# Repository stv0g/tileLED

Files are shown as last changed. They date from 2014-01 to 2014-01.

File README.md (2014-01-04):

tileLED
=======

A very minimalistic driver for 8x8 LED dot matrix displays.

Based on an ATmega8 this board can drive a simple LED matrix displays. There is no real "driver" circuit on the board. We just use the GPIOs of the AVR mcu to sink/source the LED current.

According to the ATmega8 datasheet this usage is a bit out of spec, but tests with 3 Volt button cells were successful. Also 5 Volt supplies are okay.

The source code includes a simple demonstration application. Paired with a DS1820 digital temperature sensor, the display shows the current temperature and records the minimal and maximal temperature ever measured.

A Blog post on http://www.steffenvogel.de will follow.

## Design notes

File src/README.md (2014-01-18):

This is a simple demo application

#### Fuses for the ATmega8

We use the internal 8 MHz oszilator:

Low = 0xd4
High = 0xd9

use 'make fuses' to program using avrdude

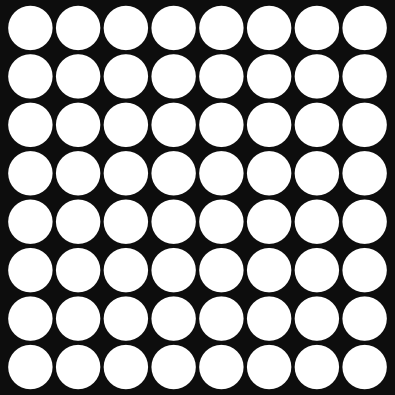
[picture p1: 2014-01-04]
schematic/v4/tile_texture.png

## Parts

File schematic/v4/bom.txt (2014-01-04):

ATmega32u4	QFN44				ok
NRF8001		QFN32				ok

micro USB					ok
3.0 V LDO VR					ok
16 Mhz Quarz / Oszillator

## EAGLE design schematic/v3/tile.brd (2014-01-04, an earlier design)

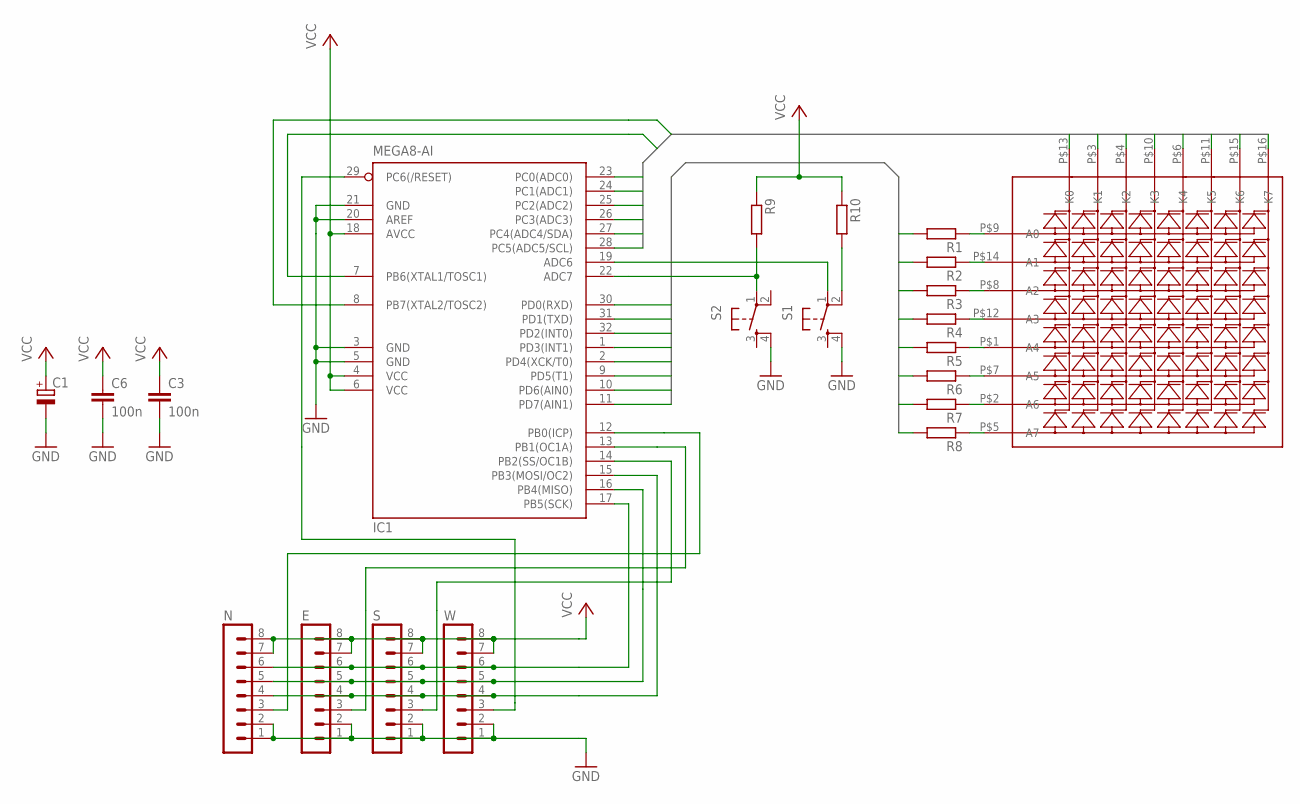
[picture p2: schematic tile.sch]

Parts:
C1: CPOL-EUB; PANASONIC_B
C3, C6: 100n; C0805
E: MA08-1
IC1: MEGA8-AI; TQFP32-08
N: MA08-1
R1, R2, R3, R4, R5, R6, R7, R8, R9, R10: R-EU_M0805; M0805
S: MA08-1
S1, S2: TAC_SWITCHSMD; TACTILE_SWITCH_SMD
U$1: LED-MATRIX
W: MA08-1

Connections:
A0: IC1.30 (PD0(RXD)), R1.2
A1: IC1.31 (PD1(TXD)), R2.2
A2: IC1.32 (PD2(INT0)), R3.2
A3: IC1.1 (PD3(INT1)), R4.2
A4: IC1.2 (PD4(XCK/T0)), R5.2
A5: IC1.9 (PD5(T1)), R6.2
A6: IC1.10 (PD6(AIN0)), R7.2
A7: IC1.11 (PD7(AIN1)), R8.2
GND: C1.-, C3.2, C6.2, E.1, E.2, IC1.3 (GND), IC1.5 (GND), IC1.20 (AREF), IC1.21 (GND), N.1, N.2, S.1, S.2, S1.4, S2.4, W.1, W.2
K0: IC1.23 (PC0(ADC0)), U$1.P$13 (K0)
K1: IC1.24 (PC1(ADC1)), U$1.P$3 (K1)
K2: IC1.25 (PC2(ADC2)), U$1.P$4 (K2)
K3: IC1.26 (PC3(ADC3)), U$1.P$10 (K3)
K4: IC1.27 (PC4(ADC4/SDA)), U$1.P$6 (K4)
K5: IC1.28 (PC5(ADC5/SCL)), U$1.P$11 (K5)
K6: IC1.7 (PB6(XTAL1/TOSC1)), U$1.P$15 (K6)
K7: IC1.8 (PB7(XTAL2/TOSC2)), U$1.P$16 (K7)
unnamed: IC1.19 (ADC6), S1.1
unnamed: IC1.22 (ADC7), R9.2, S2.1
unnamed: E.4, IC1.15 (PB3(MOSI/OC2)), N.4, S.4, W.4
unnamed: R10.2, S1.2
unnamed: IC1.14 (PB2(SS/OC1B)), S.3
unnamed: E.6, IC1.17 (PB5(SCK)), N.6, S.6, W.6
unnamed: IC1.29 (PC6(/RESET)), W.3
unnamed: E.5, IC1.16 (PB4(MISO)), N.5, S.5, W.5
unnamed: IC1.12 (PB0(ICP)), N.3
unnamed: E.3, IC1.13 (PB1(OC1A))
NA0: R1.1, U$1.P$9 (A0)
NA1: R2.1, U$1.P$14 (A1)
NA2: R3.1, U$1.P$8 (A2)
NA3: R4.1, U$1.P$12 (A3)
NA4: R5.1, U$1.P$1 (A4)
NA5: R6.1, U$1.P$7 (A5)
NA6: R7.1, U$1.P$2 (A6)
NA7: R8.1, U$1.P$5 (A7)
VCC: C1.+, C3.1, C6.1, E.7, E.8, IC1.4 (VCC), IC1.6 (VCC), IC1.18 (AVCC), N.7, N.8, R9.1, R10.1, S.7, S.8, W.7, W.8

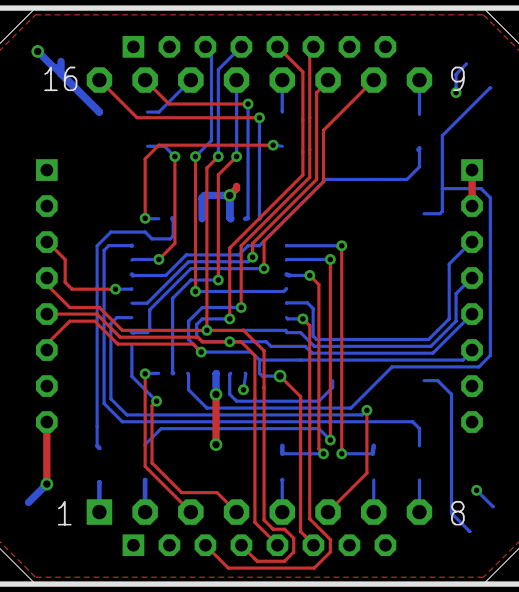
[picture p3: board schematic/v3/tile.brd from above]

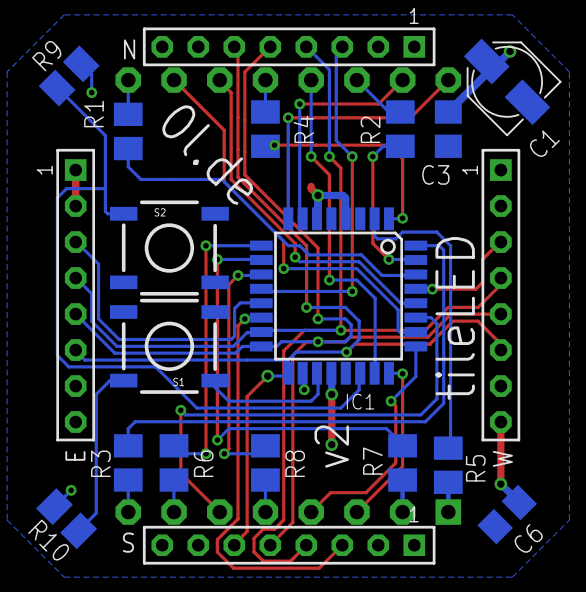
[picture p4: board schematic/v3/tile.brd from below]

Board: 2 copper layers, 21 parts (20 on the bottom side), 36 nets.

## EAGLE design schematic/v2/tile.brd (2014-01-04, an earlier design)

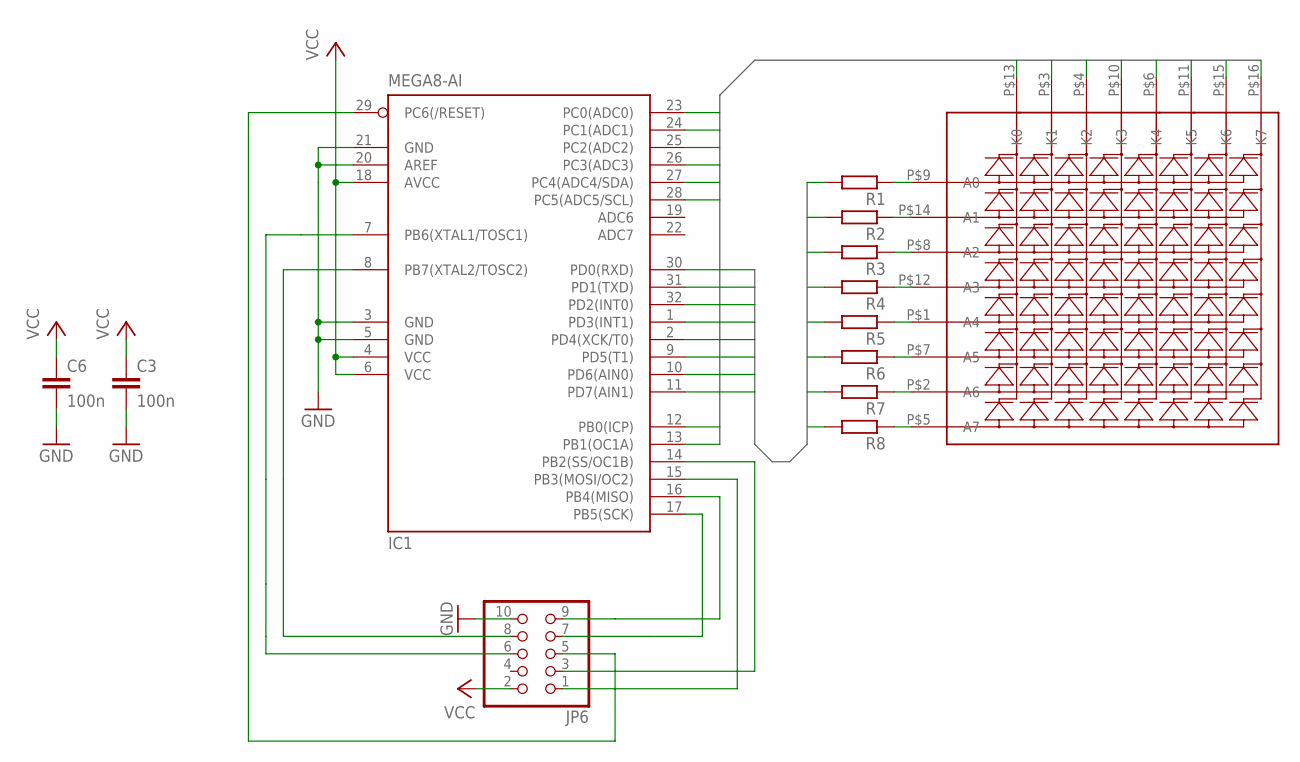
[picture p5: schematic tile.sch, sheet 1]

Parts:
C3, C6: 100n; C0805
IC1: MEGA8-AI; TQFP32-08
JP6: PINHD-2X5_2.54; 2X05
R1, R2, R3, R4, R5, R6, R7, R8: R-EU_M0805; M0805
U$1: LED-MATRIX

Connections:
A0: IC1.30 (PD0(RXD)), R1.1, R1.2, U$1.P$9 (A0)
A1: IC1.31 (PD1(TXD)), R2.1, R2.2, U$1.P$14 (A1)
A2: IC1.32 (PD2(INT0)), R3.1, R3.2, U$1.P$8 (A2)
A3: IC1.1 (PD3(INT1)), R4.1, R4.2, U$1.P$12 (A3)
A4: IC1.2 (PD4(XCK/T0)), R5.1, U$1.P$1 (A4)
A5: IC1.9 (PD5(T1)), R5.2, R6.1, R6.2, U$1.P$7 (A5)
A6: IC1.10 (PD6(AIN0)), R7.1, R7.2, U$1.P$2 (A6)
A7: IC1.11 (PD7(AIN1)), R8.1, R8.2, U$1.P$5 (A7)
GND: C3.2, C6.2, IC1.3 (GND), IC1.5 (GND), IC1.20 (AREF), IC1.21 (GND), JP6.10; also elsewhere on the board
K0: IC1.23 (PC0(ADC0)), U$1.P$13 (K0)
K1: IC1.24 (PC1(ADC1)), U$1.P$3 (K1)
K2: IC1.25 (PC2(ADC2)), U$1.P$4 (K2)
K3: IC1.26 (PC3(ADC3)), U$1.P$10 (K3)
K4: IC1.27 (PC4(ADC4/SDA)), U$1.P$6 (K4)
K5: IC1.28 (PC5(ADC5/SCL)), U$1.P$11 (K5)
K6: IC1.12 (PB0(ICP)), U$1.P$15 (K6)
K7: IC1.13 (PB1(OC1A)), U$1.P$16 (K7)
unnamed: IC1.17 (PB5(SCK)), JP6.7
unnamed: IC1.8 (PB7(XTAL2/TOSC2)), JP6.8
unnamed: IC1.29 (PC6(/RESET)), JP6.5
unnamed: IC1.14 (PB2(SS/OC1B)), JP6.3
unnamed: IC1.16 (PB4(MISO)), JP6.9
unnamed: IC1.15 (PB3(MOSI/OC2)), JP6.1
unnamed: IC1.7 (PB6(XTAL1/TOSC1)), JP6.6
VCC: C3.1, C6.1, IC1.4 (VCC), IC1.6 (VCC), IC1.18 (AVCC), JP6.2; also elsewhere on the board

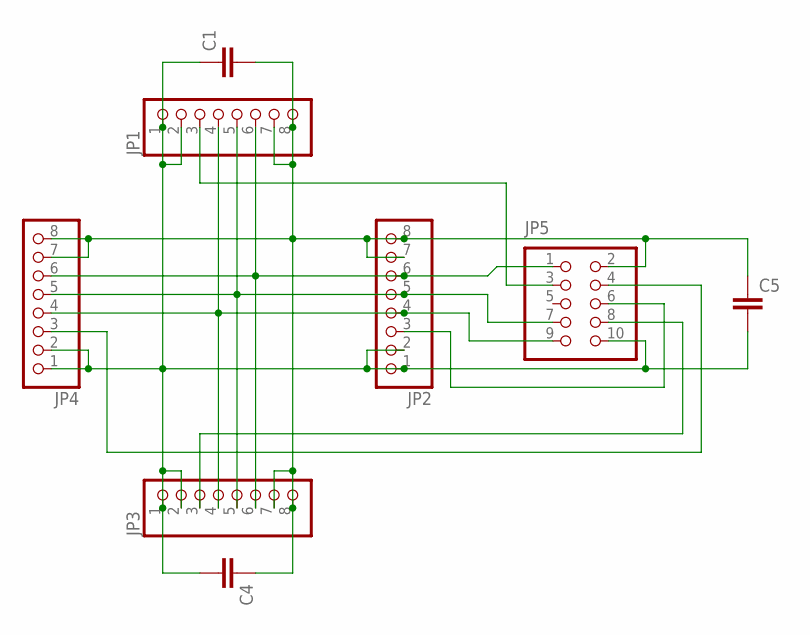
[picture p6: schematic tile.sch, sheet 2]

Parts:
C1, C4, C5: C-EUC0805; C0805
JP1, JP2, JP3, JP4: PINHD-1X8_2.00; 1X08M
JP5: PINHD-2X5_2.54; 2X05

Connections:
GND: C1.1, C4.2, C5.2, JP1.1, JP1.2, JP2.1, JP2.2, JP3.1, JP3.2, JP4.1, JP4.2, JP5.10; also elsewhere on the board
unnamed: JP4.3, JP5.4
unnamed: JP3.3, JP5.8
unnamed: JP2.3, JP5.6
unnamed: JP1.3, JP5.3
unnamed: JP1.6, JP2.6, JP3.6, JP4.6, JP5.1
unnamed: JP1.5, JP2.5, JP3.5, JP4.5, JP5.7
unnamed: JP1.4, JP2.4, JP3.4, JP4.4, JP5.9
VCC: C1.2, C4.1, C5.1, JP1.7, JP1.8, JP2.7, JP2.8, JP3.7, JP3.8, JP4.7, JP4.8, JP5.2; also elsewhere on the board

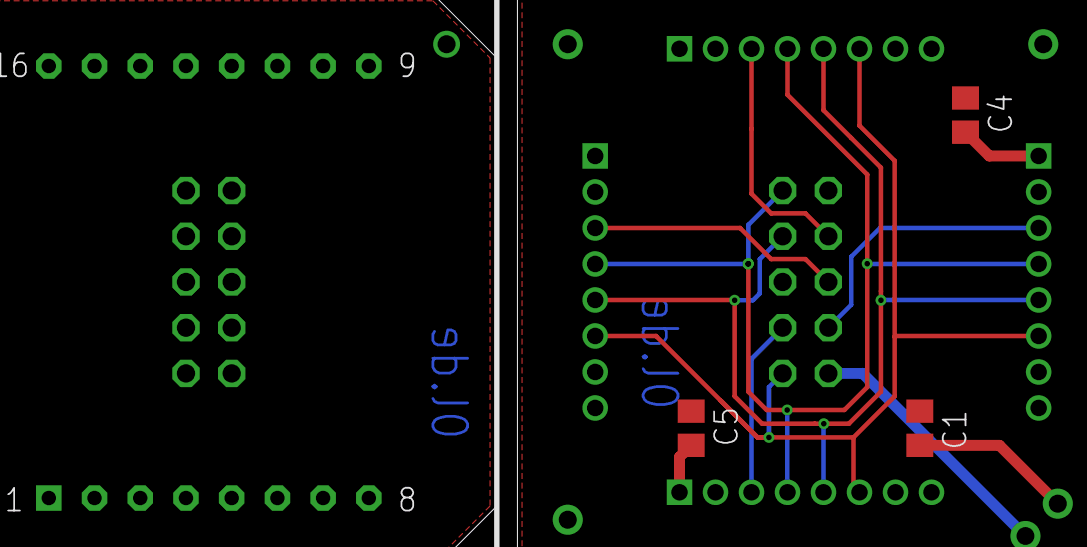
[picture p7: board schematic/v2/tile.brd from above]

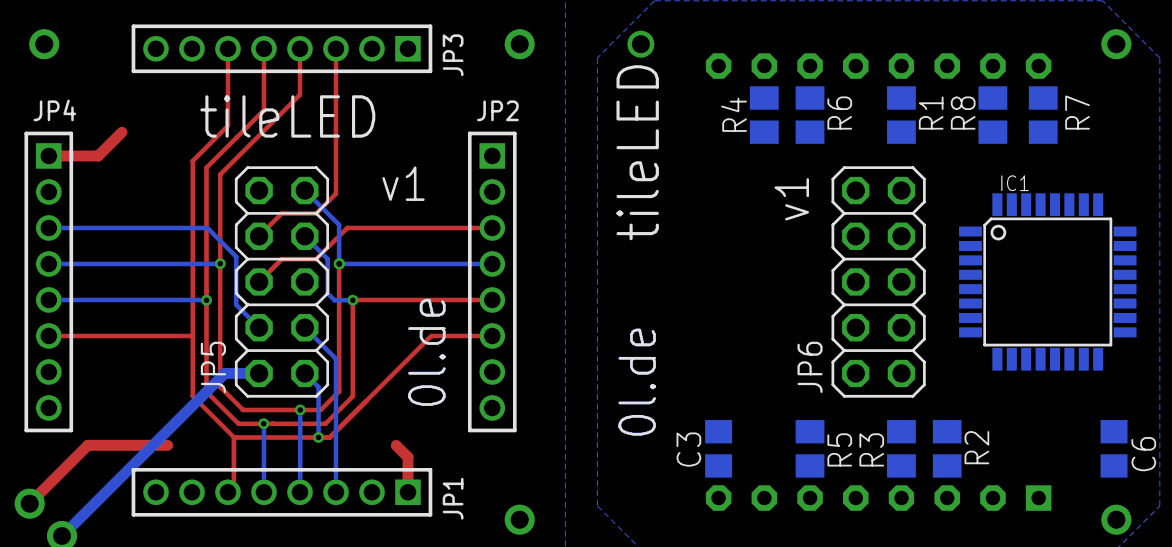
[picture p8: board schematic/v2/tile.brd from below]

Board: 2 copper layers, 21 parts (17 on the bottom side), 32 nets.

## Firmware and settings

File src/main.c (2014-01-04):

#include <stdint.h>
#include <string.h>
#include <avr/io.h>
#include <avr/interrupt.h>

#include "font.h"
#include "ds1820.h"

#define BUFLEN (8*64)

const char *msg = "Frohe Weihnachten und einen guten Rutsch wuenscht euch Steffen";

volatile float temp_cur;
volatile float temp_min = 1e6;
volatile float temp_max = -1e6;

volatile uint8_t buffer[BUFLEN] = { 0 };
volatile uint8_t scroll = 0;
volatile uint8_t len = 0;


void set_buffer(char* text) {
	uint8_t a = 0, b, c;

	for (c = 0; c < 8; c++)
		buffer[a++] = 0;

	for (b = 0; text[b]; b++) {
		for (c = 0; a < BUFLEN && c < FONT_WIDTH && font[text[b] - ' '][c] != 0xff; c++, a++) {
			buffer[a] = font[text[b] - ' '][c];
		}

		buffer[a++] = 0;
	}

	len = a;

	for (c = 0; c < 8; c++)
		buffer[a++] = 0;
}

void init(void) {
	/* IO Ports */
	DDRB = 0xc0; /* cathodes 6..7 */
	DDRC = 0x3f; /* cathodes 0..5 */
	DDRD = 0xff; /* anodes  */

	/* Timer2 */
	TCCR2 |= (1 << WGM21) | (1 << CS22) | (1 << CS21); /* prescaler = 256 */
	TIFR |= (1 << OCF2);
	OCR2 = 90; /* interrupt = ??? Hz */

	/* Timer1 */
	TCCR1A = 0;
	TCCR1B = (1 << CS12) | (1 << CS10); /* prescaler = 1024 => 0,12 Hz = 8,3s */
	TIFR |= (1 << OCF1A);
	OCR1A = (1 << 13);
}

ISR(TIMER2_COMP_vect) {
	static uint8_t cnt = 100;
	uint8_t row = cnt % 8;

	PORTD = 0;

	PORTB |= 0xC0;
	PORTB &= ~((1 << row) & 0xC0);
	PORTC = ~((1 << row) & 0x3f);

	PORTD = *(buffer+scroll+7-row);


	if (cnt) {
		cnt--;
	}
	else {
		if (scroll == len) {
			/* stop timer2 */
			TIMSK &= ~(1 << OCIE2);

			/* start timer1 */
			TCNT1 = 0;
			TIFR |= (1 << OCF1A);
			TIMSK |= (1 << OCIE1A);
		}
		else {
			scroll++;
		}

		cnt = 100;
	}
}

ISR(TIMER1_COMPA_vect) {
	static uint16_t cnt;
	static uint8_t step;
	char text[120];

	TIMSK &= ~(1 << OCIE1A); /* stop timer1 */

	if (cnt) {
		cnt--;
	}
	else {
		step++;
		step %= 6;

//		cnt = 300;
		scroll = 0;

		temp_cur = ds1820_read_temp(PB2);

		/* update minimum/maximum */
		if (temp_cur > temp_max) {
			temp_max = temp_cur;
		}
		if (temp_cur < temp_min) {
			temp_min = temp_cur;
		}

		switch (step) {
			case 0:
			case 2:
			case 4:
			case 6:
				snprintf(text, sizeof(text), "%.1f%cC", temp_cur, 0x80);
				set_buffer(text);
				break;
			case 1:
				snprintf(text, sizeof(text), "min %.1f%cC", temp_min, 0x80);
				set_buffer(text);
				break;
			case 3:
				snprintf(text, sizeof(text), "max %.1f%cC", temp_max, 0x80);
				set_buffer(text);
				break;
			case 5:
				set_buffer(msg);
				break;
		}


		TIFR |= (1 << OCF2);
		TIMSK |= (1 << OCIE2); /* start timer2 */
	}
}

int main(void) {
	init();
	ds1820_init(PB2);

//	set_buffer("hallo da");
	TIMSK |= (1 << OCIE2); /* start timer2 */

	sei();
	while (1);

	return 0;
}

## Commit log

2014-01-04 added first schematic version
    [tile.brd, tile.sch]
2014-01-04 added second schematic version
    [tile.brd, tile.sch]
2014-01-04 added third schematic version
    [tile.brd, tile.sch]
2014-01-18 updated gitignore and added note to fuses
2014-01-18 replaced Makefile by simpler one with fuse programming support

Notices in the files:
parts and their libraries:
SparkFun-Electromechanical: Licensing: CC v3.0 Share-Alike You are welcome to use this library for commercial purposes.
